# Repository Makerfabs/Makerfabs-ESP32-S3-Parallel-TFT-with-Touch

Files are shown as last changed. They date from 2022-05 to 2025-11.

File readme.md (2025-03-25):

# Makerfabs ESP32-S3 Parallel TFT with Touch

```c++
/*
Version:		V1.3
Author:			Vincent
Create Date:	2022/5/24
Note:
	2022/12/29	V1.3:Change wiki link.
	2022/10/7	V1.2:Add USB HID example.
	2022/10/7	V1.1:Add USB HID example.
*/
```


[toc]

# Makerfabs

[Makerfabs home page](https://www.makerfabs.com/)

[Makerfabs Wiki](https://wiki.makerfabs.com/)

# Makerfabs ESP32-S3 Parallel TFT with Touch
## Intruduce

Product Link ：[ESP32-S3 Parallel TFT with Touch 3.5'' ILI9488](https://www.makerfabs.com/esp32-s3-parallel-tft-with-touch-ili9488.html)

Wiki Link : [ESP32-S3 Parallel 3.5'' TFT with Touch](https://wiki.makerfabs.com/ESP32_S3_Parallel_3.5_TFT_with_Touch.html)

The 3.5" 320x480 TFT LCD driver is ILI9488, it uses 16bits parallel line for communication with ESP32-S3, the main clock could be up to 20MHz, make the display smooth enough for videos; You can freely use some of Mabee pins(A I2c and a IOs) with the breakout connectors, to connect the ESP32-S3 display with sensors/ actuators, suitable for IoT applications.

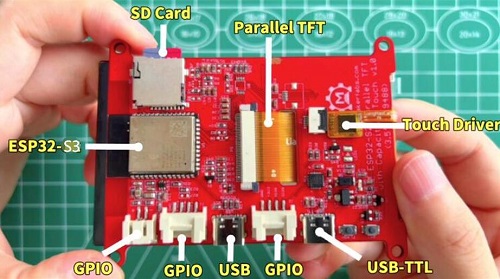
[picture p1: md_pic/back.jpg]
back


## Feature

- Wi-Fi (2.4 GHz band)
- Bluetooth Low Energy
- Dual high performance Xtensa® 32-bit LX7 CPU cores
- Ultra Low Power co-processor running either RISC-V or FSM core
- Multiple peripherals
- Built-in security hardware
- USB OTG interface
- USB Serial/JTAG Controller
- Arduino Compatible: You can play it with Arduino IDE
- LCD 3.5 inch Amorphous-TFT-LCD (Thin Film Transistor Liquid Crystal Display) for mobile-phone or handy electrical equipment
- LCD Driver: ILI9488(16bits parallel line)
- LCD Resolution: 320*480
- FT6236 Series ICs are single-chip capacitive touch panel controller IC with a built-in 16 bit enhanced Micro-controller unit (MCU)
- NS2009: A 4-wire resistive touch screen control circuit with I2C interface, which contains A 12-bit resolution A/D converter
- Power supply: 5V, Type-C USB
- Micro SD card slot on the board
- Dual USB Type-C: one for native USB and one for USB-to-UART
- Two Mabee interfaces
- Board size: 66mm * 85mm

# Code Explain

## Complier Option

- Install board : ESP32 .
- Install library : LovyanGFX library. 
- Edit the code based on the touch screen. If you use resistive screen, choice NS2009_TOUCH. If you use capacitive screen, choice FT6236_TOUCH. 
- Use type-c use cable connect USB-TTL to PC.
- Upload codes, select "ESP32-S3 DEV Module" and "UART0"

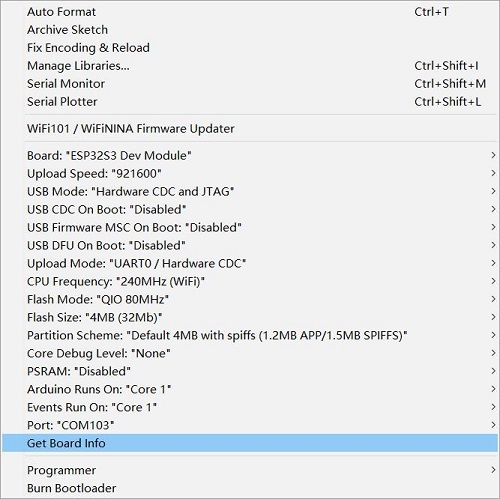
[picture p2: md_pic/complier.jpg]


## Firmware

### SD16_3.5

Factory firmware. First run the boot self-test to check the hardware. Press down the middle of the touch screen as prompted to display a LOGO picture on the SD card. Finally, print the touch coordinates in the serial port.

## Example

### touch_keyboard

The ESP32S3 native USB is used, which can be used as a USB HID to simulate a keyboard.

You can input text, key combination, enter key, and connect to the NTP server through WiFi, output real-time time.

### touch_keyboard V2.0

Added an inherited three custom keyboard keyboard Demo, including text input + key combination, numeric keypad, arrow keys + space.

### PDQgraphicstest

Arduino GFX Library display demo.

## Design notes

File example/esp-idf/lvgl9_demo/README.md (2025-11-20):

## How to use example

Before you begin, please ensure that esp-idf is installed on your computer. If not, click [Get Started with esp-idf](https://wiki.makerfabs.com/Get_Start_with_ESP-IDF.html) to complete the installation.

Launch the project in Visual Studio Code.

Set espressif Device Target **ESP32S3**



Use USB-C to connect the board and PC, select the corresponding port and Flash Device.



**Result**

lvgl_widgets

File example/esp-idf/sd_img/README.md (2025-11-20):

## How to use example

> It is recommended to use the [conversion tool](https://lvgl.io/tools/imageconverter) provided by LVGL to convert the image into a bin file, and then store it on the SD card. This way, the CPU does not need to decode the image in real time, thereby improving the refresh speed.

Before you begin, please ensure that esp-idf is installed on your computer. If not, click [Get Started with esp-idf](https://wiki.makerfabs.com/Get_Start_with_ESP-IDF.html) to complete the installation.

Launch the project in Visual Studio Code.

Set espressif Device Target **ESP32S3**



Use USB-C to connect the board and PC, select the corresponding port and Flash Device.



**Result**:

sd_img

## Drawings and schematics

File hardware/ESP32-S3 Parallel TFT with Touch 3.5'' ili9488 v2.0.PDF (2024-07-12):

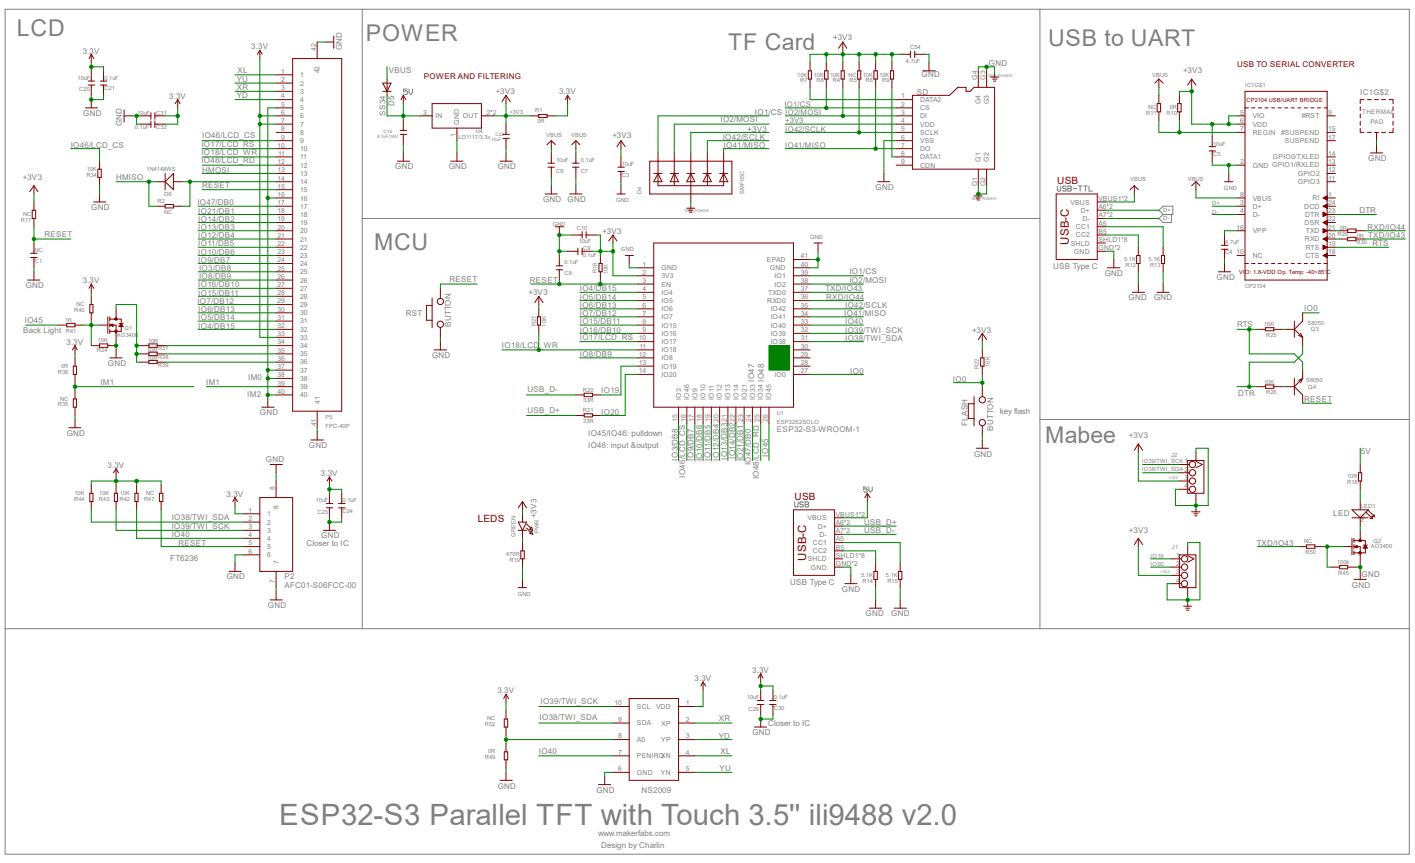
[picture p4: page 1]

USB Type C TF Card

USB TO SERIAL CONVERTER

VIO: 1.8-VDD Op. Temp: -40~85°C USB⁻C USB⁻C

ESP32-S3 Parallel TFT with Touch 3.5'' ili9488 v2.0

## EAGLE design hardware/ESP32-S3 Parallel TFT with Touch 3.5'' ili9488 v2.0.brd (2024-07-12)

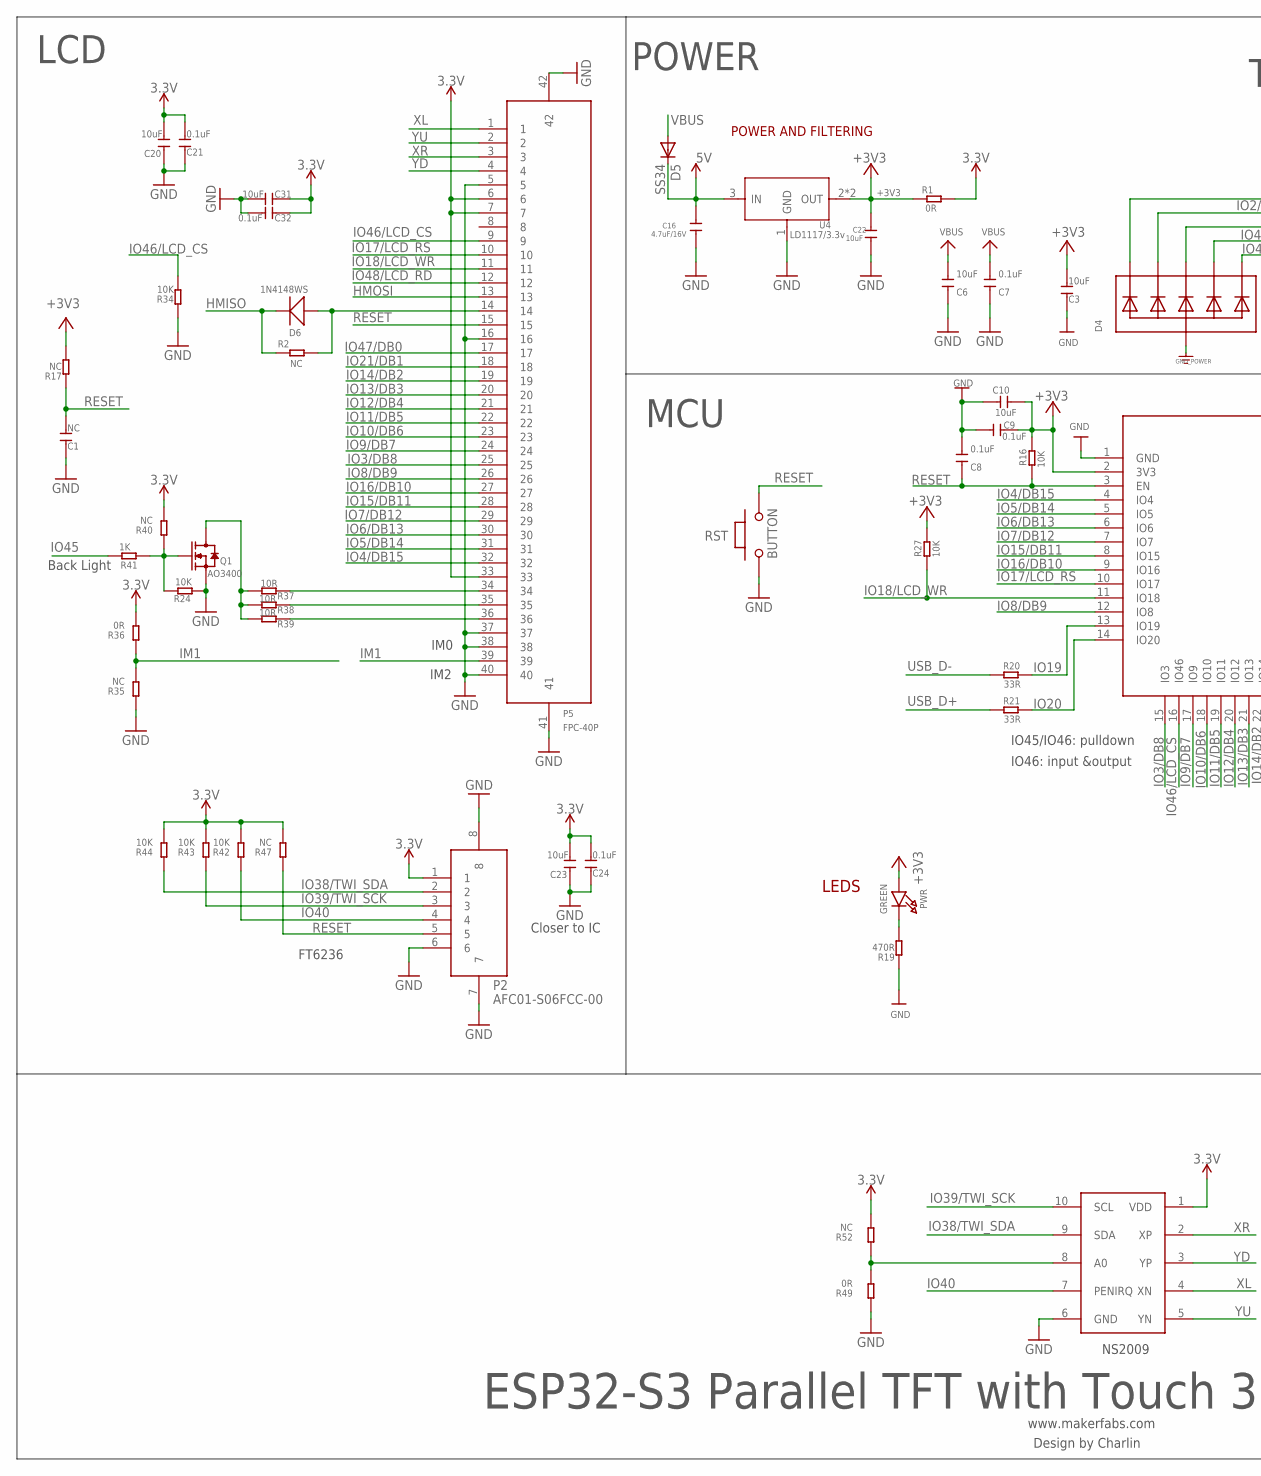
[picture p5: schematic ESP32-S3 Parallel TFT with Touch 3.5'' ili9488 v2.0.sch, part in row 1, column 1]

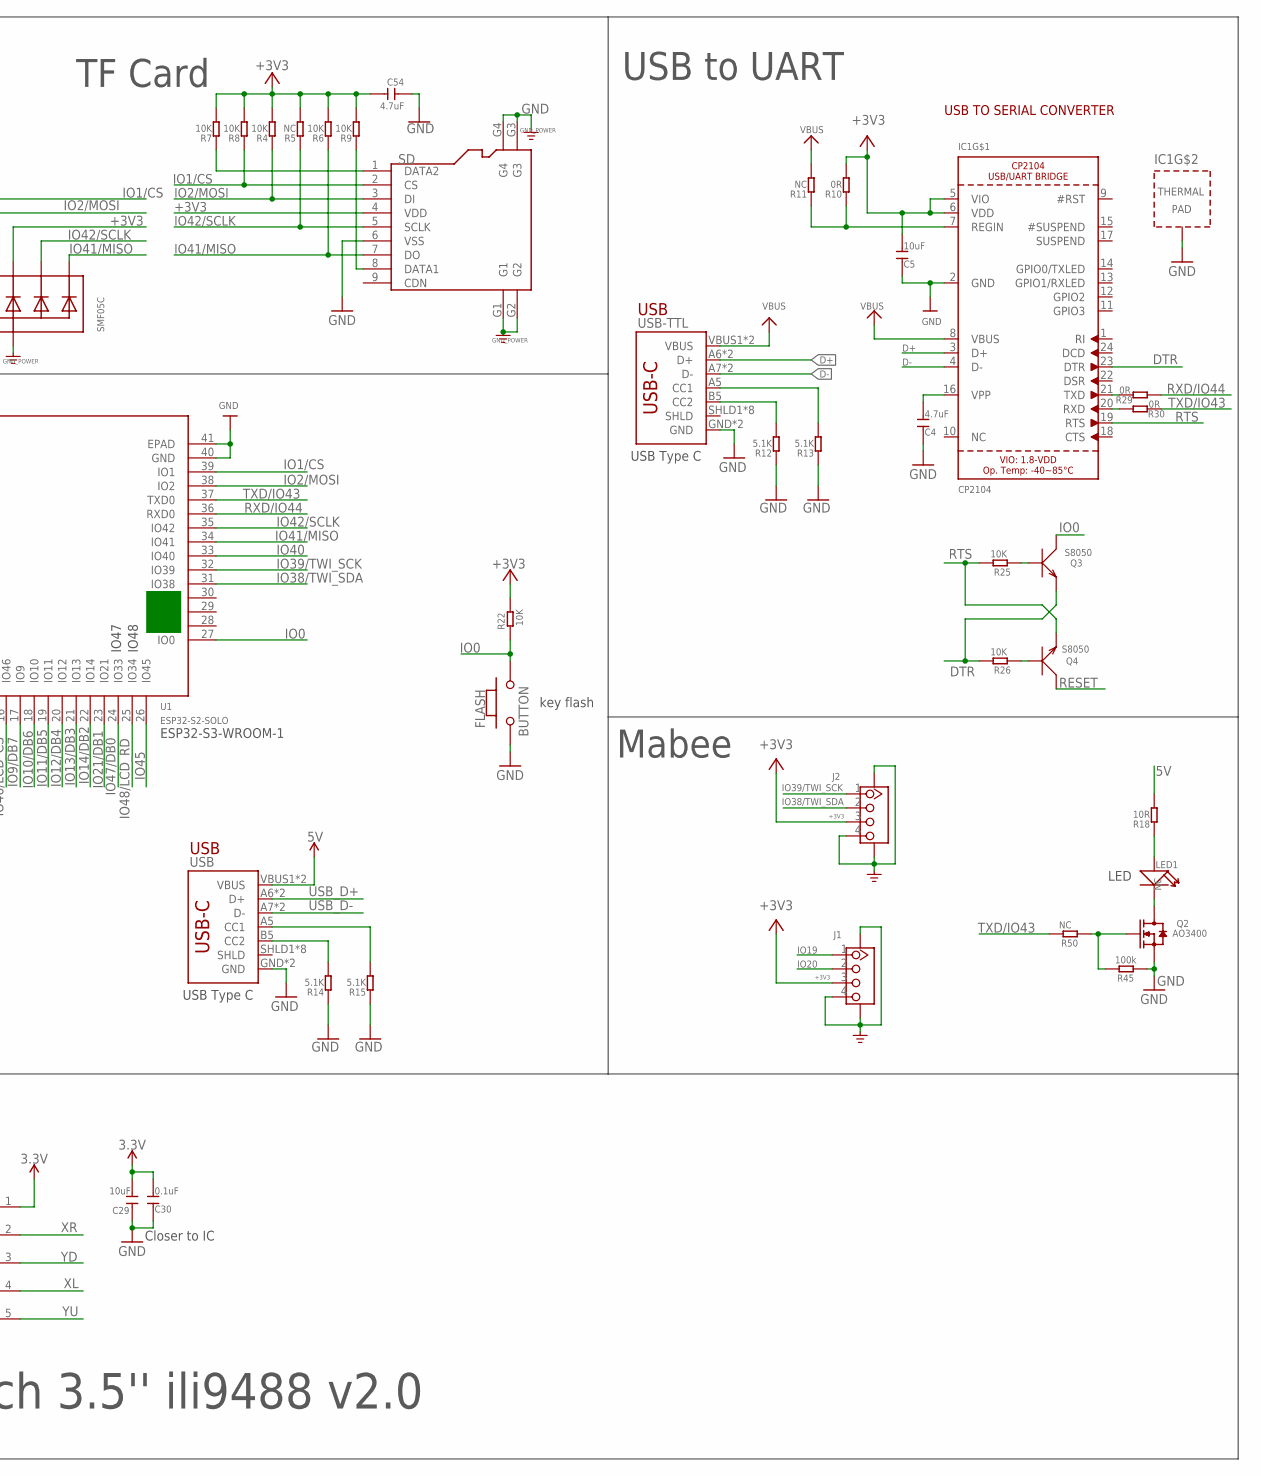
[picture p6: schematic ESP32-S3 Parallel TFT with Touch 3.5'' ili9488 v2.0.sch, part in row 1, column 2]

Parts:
C1: NC; DISCRETE_C0603
C3, C5, C6, C10, C20, C23, C29, C31: 10uF; DISCRETE_C0603
C4, C54: 4.7uF; DISCRETE_C0603
C7, C8, C9, C21, C24, C30, C32: 0.1uF; DISCRETE_C0603
C16: 4.7uF/16V; 0603
C22: 10uF; 0603
D4: SMF05C; SOT363
D5: SS34; DO-214AC
D6: 1N4148WS; SOD323
FLASH: BUTTON; 157SW
IC1: CP2104; QFN24_4MM_SMSC
J1, J2: GROVE-CONNECTOR-SMD'90D'; HW4-SMD-2.0-90D
LED1: NC; DISCRETE_LED-3528
P2: AFC01-S06FCC-00; SMD8-50P-740L535W
P5: FPC-40P; SMD42-50P-2560L490W
PWR: GREEN; CHIPLED_0805_NOOUTLINE
Q1, Q2: AO3400; SOT23@1
Q3, Q4: S8050; SOT23
R1, R29, R30: 0R; R0603
R2, R50: NC; R0603
R4, R6, R7, R8, R9, R24, R34, R42, R43, R44: 10K; DISCRETE_R0603
R5, R11, R17, R35, R40, R47, R52: NC; DISCRETE_R0603
R10, R36, R49: 0R; DISCRETE_R0603
R12, R13, R14, R15: 5.1K; DISCRETE_R0603
R16, R22, R25, R26, R27: 10K; R0603
R18, R37, R38, R39: 10R; DISCRETE_R0603
R19: 470R; DISCRETE_R0603
R20, R21: 33R; R0603
R41: 1K; DISCRETE_R0603
R45: 100k; R0603
RST: BUTTON; 157SW
SD: HOLDER-MICROSD-9P; 9P-SMD-W/-RING
U1: ESP32­S2­SOLO; ESP32-­S2-­SOLO
U4: LD1117/3.3v; SOT89
U8: NS2009; MSOP10
USB: USB_C5; USB-C-16P-5
USB-TTL: USB_C5; USB-C-16P-5

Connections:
3.3V: C20.2, C21.2, C23.2, C24.2, C29.2, C30.2, C31.1, C32.1, P2.1, P5.6, P5.7, P5.33, R1.2, R36.2, R40.2, R42.2, R43.2, R44.2, R47.2, R52.2, U8.1 (VDD)
5V: C16.1, D5.C, R18.2, U4.3 (IN), USB.VBUS1 (VBUS), USB.VBUS2 (VBUS)
+3V3: C3.2, C5.2, C9.1, C10.1, C22.1, C54.2, D4.4 (C3), IC1.5 (VIO), IC1.6 (VDD), J1.3, J2.3, PWR.A, R1.1, R4.2, R5.2, R6.2, R7.2, R8.2, R9.2, R10.2, R16.2, R17.2, R22.2, R27.2, SD.4 (VDD), U1.2 (3V3), U4.2 (OUT), U4.4 (OUT)
D+: IC1.3 (D+), USB-TTL.A6 (D+), USB-TTL.B6 (D+)
D-: IC1.4 (D-), USB-TTL.A7 (D-), USB-TTL.B7 (D-)
DTR: IC1.23 (DTR), Q3.2 (E), R26.2
GND: C1.1, C3.1, C4.1, C5.1, C6.1, C7.1, C8.2, C9.2, C10.2, C16.2, C20.1, C21.1, C22.2, C23.1, C24.1, C29.1, C30.1, C31.2, C32.2, C54.1, D4.2 (A), FLASH.1, IC1.2 (GND), IC1.THERM (TP), J1.4, J1.SS1, J1.SS2, J2.4, J2.SS1, J2.SS2, P2.6, P2.7, P2.8, P5.5, P5.16, P5.37, P5.38, P5.40, P5.41, P5.42, Q1.2 (S), Q2.2 (S), R12.1, R13.1, R14.1, R15.1, R19.1, R24.1, R34.1, R35.1, R45.1, R49.1, RST.1, SD.6 (VSS), SD.G1, SD.G2, SD.G3, SD.G4, U1.1 (GND), U1.40 (GND), U1.41 (EPAD), U4.1 (GND), U8.6 (GND), USB.GND, USB.GND2 (GND), USB-TTL.GND, USB-TTL.GND2 (GND)
HMISO: D6.-, R2.1
HMOSI: P5.13
IM1: P5.39, R35.2, R36.1
IO0: FLASH.2, Q3.3 (C), R22.1, U1.27 (IO0)
IO1/CS: D4.1 (C1), R8.1, SD.2 (CS), U1.39 (IO1)
IO2/MOSI: D4.3 (C2), R4.1, SD.3 (DI), U1.38 (IO2)
IO3/DB8: P5.25, U1.15 (IO3)
IO4/DB15: P5.32, U1.4 (IO4)
IO5/DB14: P5.31, U1.5 (IO5)
IO6/DB13: P5.30, U1.6 (IO6)
IO7/DB12: P5.29, U1.7 (IO7)
IO8/DB9: P5.26, U1.12 (IO8)
IO9/DB7: P5.24, U1.17 (IO9)
IO10/DB6: P5.23, U1.18 (IO10)
IO11/DB5: P5.22, U1.19 (IO11)
IO12/DB4: P5.21, U1.20 (IO12)
IO13/DB3: P5.20, U1.21 (IO13)
IO14/DB2: P5.19, U1.22 (IO14)
IO15/DB11: P5.28, U1.8 (IO15)
IO16/DB10: P5.27, U1.9 (IO16)
IO17/LCD_RS: P5.10, U1.10 (IO17)
IO18/LCD_WR: P5.11, R27.1, U1.11 (IO18)
IO19: J1.1, R20.2, U1.13 (IO19)
IO20: J1.2, R21.2, U1.14 (IO20)
IO21/DB1: P5.18, U1.23 (IO21)
IO38/TWI_SDA: J2.2, P2.2, R44.1, U1.31 (IO38), U8.9 (SDA)
IO39/TWI_SCK: J2.1, P2.3, R43.1, U1.32 (IO39), U8.10 (SCL)
IO40: P2.4, R42.1, U1.33 (IO40), U8.7 (PENIRQ)
IO41/MISO: D4.6 (C5), R6.1, SD.7 (DO), U1.34 (IO41)
IO42/SCLK: D4.5 (C4), R5.1, SD.5 (SCLK), U1.35 (IO42)
IO45: R41.2, U1.26 (IO45)
IO46/LCD_CS: P5.9, R34.2, U1.16 (IO46)
IO47/DB0: P5.17, U1.24 (IO33)
IO48/LCD_RD: P5.12, U1.25 (IO34)
unnamed: C4.2, IC1.16 (VPP)
unnamed: Q4.1 (B), R26.1
unnamed: Q3.1 (B), R25.1
unnamed: D6.+, P5.14, R2.2
unnamed: Q2.1 (G), R45.2, R50.1
unnamed: R15.2, USB.A5 (CC1)
unnamed: PWR.C, R19.2
unnamed: LED1.1 (+), R18.1
unnamed: LED1.2 (-), Q2.3 (D)
unnamed: R13.2, USB-TTL.A5 (CC1)
unnamed: R12.2, USB-TTL.B5 (CC2)
unnamed: IC1.7 (REGIN), R10.1, R11.1
unnamed: R14.2, USB.B5 (CC2)
unnamed: IC1.21 (TXD), R29.2
unnamed: IC1.20 (RXD), R30.2
unnamed: P5.34, R37.1
unnamed: P5.35, R38.1
unnamed: P5.36, R39.1
unnamed: Q1.1 (G), R24.2, R40.1, R41.1
unnamed: Q1.3 (D), R37.2, R38.2, R39.2
unnamed: R49.2, R52.1, U8.8 (A0)
unnamed: R7.1, SD.1 (DATA2)
unnamed: R9.1, SD.8 (DATA1)
RESET: C1.2, C8.1, P2.5, P5.15, Q4.3 (C), R16.1, R17.1, R47.1, RST.2, U1.3 (EN)
RTS: IC1.19 (RTS), Q4.2 (E), R25.2
RXD/IO44: R29.1, U1.36 (RXD0)
TXD/IO43: R30.1, R50.2, U1.37 (TXD0)
USB_D+: R21.1, USB.A6 (D+), USB.B6 (D+)
USB_D-: R20.1, USB.A7 (D-), USB.B7 (D-)
VBUS: C6.2, C7.2, D5.A, IC1.8 (VBUS), R11.2, USB-TTL.VBUS1 (VBUS), USB-TTL.VBUS2 (VBUS)
XL: P5.1, U8.4 (XN)
XR: P5.3, U8.2 (XP)
YD: P5.4, U8.3 (YP)
YU: P5.2, U8.5 (YN)

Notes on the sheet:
www.makerfabs.com
Design by Charlin
USB
LEDS
POWER AND FILTERING
USB TO SERIAL CONVERTER
key flash
ESP32-S3 Parallel TFT with Touch 3.5'' ili9488 v2.0
POWER
USB to UART
USB Type C
TF Card
LED
NS2009
FT6236
Closer to IC
Back Light
IM0
IM2
IO45/IO46: pulldown
IO46: input &output
Mabee
LCD
MCU
ESP32-S3-WROOM-1
IO47
IO48

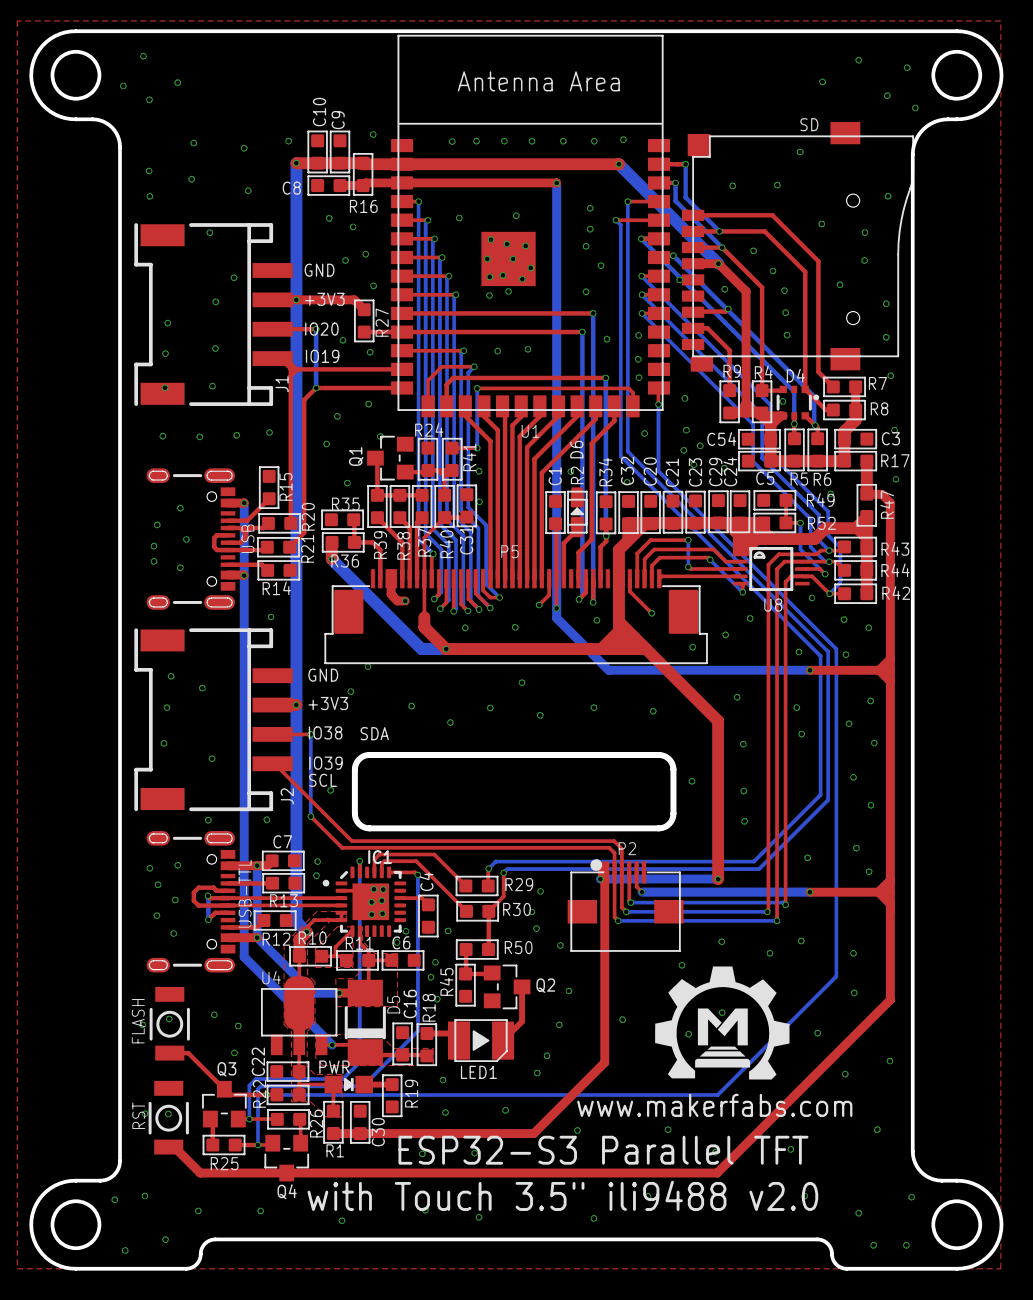
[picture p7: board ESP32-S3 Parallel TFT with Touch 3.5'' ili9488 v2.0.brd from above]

Board: 2 copper layers, 66.1 x 84.3 mm, 86 parts (0 on the bottom side), 74 nets.

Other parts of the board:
U$1: MAKERFABS_0.3

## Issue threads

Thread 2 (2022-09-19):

What type of connector is the 4-pin?

jonsmirl, 2022-09-19:
It is not microJST, I tried that. The 2-pin is microJST.

jayv, 2023-12-09:
@jonsmirl did you ever find out? before I solder a 2.5 JST connector to the back of those?

jonsmirl, 2023-12-10:
I think it was this one:
https://www.amazon.com/gp/product/B01CNZ9RJO/ref=ppx_yo_dt_b_search_asin_title

jayv, 2023-12-10:
Thanks! I’ve also come to learn about the “Grove” connector effort, turns out I already have some compatible cables from another IOT kit. Thx!

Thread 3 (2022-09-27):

Improved display driver w/ i8080 acceleration

codewitch-honey-crisis, 2022-09-27:
Hey folks! Great product, love it!

However, your firmware doesn't really take advantage of its performance features.

You use LoyvanGFX to do the display, but it's not DMA capable, and bit bangs the pins, but the S3 has a hardware i8080 parallel driver.

I wrote a new graphics driver to use it.

I got 37 fps with your firmware running LVGL benchmarks

I got 58 fps with my driver.

If you're interested, ping me back and I'll fork and do a pull request with the improved code.

nstansbury, 2023-08-17:
@codewitch-honey-crisis Did you submit a PR for these changes? This looks like an unmaintained codebase, so if you have forked this please share

codewitch-honey-crisis, 2023-08-17:
I haven't. I suppose I could. I didn't go through the trouble of forking the makerfabs code because I have my own libs for all of its hardware. The key to better performance is to ditch Lovyan and use the ESP LCD Panel API directly, via calling into the ESP-IDF.

Ldalvik, 2023-08-19:
You'd be doing a huge favor to tons of future projects if you managed to write a good driver for this specific device, it's always disappointing seeing these kinds of things not being used to the full potentially.

codewitch-honey-crisis, 2023-08-19:
I linked to a driver in the comment you responded to.

Ldalvik, 2023-08-19:
Oh wow, I completely glanced over that and thought you only had a platformIO version. I might try to port it myself if you haven't already planned on it, I'd love to be able to write simpler code using the faster refresh rate. Is playing a video from the SD card affected by your code too?

codewitch-honey-crisis, 2023-08-19:
It is a platformIO library, but it can be used without PIO. You just need to put the two C files in the project somehow.

jonsmirl, 2024-04-11:
LCD and touch are directly supported by IDF and Component registry now.
https://github.com/jonsmirl/esp_idf_makerfab

It is very similar to your code.

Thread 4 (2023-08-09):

Touch not rotating

phpbbireland, 2023-08-09:
In the _**touch_keyboard_v2.ino**_ file, I rotated the display in **SPI_9488.h** to landscape i.e., ```cfg.offset_rotation = 1;```
I edited the code to display buttons in a 4x3 layout in (landscape mode), everything is resized and fits neatly, there's just one problem... the touch appears to return position as if in portrait mode...

Is there a method to tell the touch to rotate too?

Mike

phpbbireland, 2023-08-19:
I have overcome this by editing my code, so I guess I will close the issue...

Closed 2023-08-19.

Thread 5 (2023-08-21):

Compile error

phpbbireland, 2023-08-21:
Compile error in:
Makerfabs-ESP32-S3-Parallel-TFT-with-Touch-main/example/touch_keyboard_v2/

```
'Bus_Parallel16' in namespace 'lgfx' does not name a type
```

Everything working fine for the SPI version...
Any help appreciated...

phpbbireland, 2023-08-23:
Appears eyesight is failing... it was S2 not S3 board... apologies...
Now it compiles fine but I am getting a white screen, back to the drawing board...

Closed 2023-08-23.

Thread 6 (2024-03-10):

Esp32 and 3.5inch ili9488 16bit interface

Kiara-Mugambi, 2024-03-10:
Am trying to obtain the code between esp and the TFT that uses 16bit interface and ft6236 capacitive touch panel

Kiara-Mugambi, 2024-03-11:
Am trying to obtain the code between esp and the TFT that uses 16bit interface and ft6236 capacitive touch panel

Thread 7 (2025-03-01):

ESP32-S3 Parallel TFT with Touch 3.5'' ili9488 - SPK connector?

Dario-Ciceri, 2025-03-01:
Hello, I noticed that there is an SPK connector on the board, and I guess it is therefore possible to connect a speaker. However, I cannot find in the schematic what PINs this connector is connected to.

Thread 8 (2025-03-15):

Repeated Restarts or Blank White Display - Version 1.0

HopWorks, 2025-03-15:
I tried running the two examples (touch_keyboard and touch_keyboard_v2) on my  Makerfabs-ESP32-S3-Parallel-TFT-with-Touch 3.5" Version 1.0 (WROOM1 N16R2) with current libraries and the ESP32S3 device reboots repeatedly using both PlatformIO and Arduino IDE. I then rolled back to the library versions shown in the FAQ at [https://wiki.makerfabs.com/MaTouch_S3_Parallel_3.5_TFT_with_Touch.html#faq](url) and after correcting the spell-check errors (defualt to default) I flashed and no more restarts but I get a white screen with nothing displayed. The serial monitor still shows feedback when I press portions of the screen, telling me that the code did not crash and the touch portion is working.

I suspect changes in the wiring with the upgrade to Version 2.0 as noted in the FAQ.
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

Is this the cause of my issues? If so, where is WR, RS, and CS statically declared in the libraries? I cannot find any declarations in the example code. Thanks

HopWorks, 2025-03-15:
I solved it.  Since I had seen LCD_CS and LCD_BLK defined separately, I tried defining LCD_WR and LCD_RS in the main code and in the header file to see if that would override but it did not.

The header file `Parallel16_9488.h` (LGFX class) needs to be changed back to the correct pin settings for the version 1.0 board,
after `class LGFX : public lgfx::LGFX_Device`...
`            //cfg.pin_wr = 18; // SETTING FOR BOARD VERSION 2.0
            cfg.pin_wr = 35; // pin number to which WR is connected
            cfg.pin_rd = 48; // pin number connecting RD
            //cfg.pin_rs = 17; // SETTING FOR BOARD VERSION 2.0
            cfg.pin_rs = 36; // pin number connecting RS (D/C)`

The library is found in both keyboard examples. The settings are also in another library `S3_Parallel16_ili9488.h` in the `ESP32S3_SGP30_WEBSERVER_V1.2` example.

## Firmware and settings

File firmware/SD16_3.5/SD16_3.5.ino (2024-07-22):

#define LGFX_USE_V1

#include "FS.h"
#include "SD.h"
#include "SPI.h"
#include <LovyanGFX.hpp>

#define I2C_SCL 39
#define I2C_SDA 38

//#define NS2009_TOUCH  //Resistive screen driver
#define FT6236_TOUCH //Capacitive screen driver

#ifdef NS2009_TOUCH
#include "NS2009.h"
const int i2c_touch_addr = NS2009_ADDR;
#define get_pos ns2009_pos
#endif

#ifdef FT6236_TOUCH
#include "FT6236.h"
const int i2c_touch_addr = TOUCH_I2C_ADD;
#define get_pos ft6236_pos
#endif

#define SPI_MOSI 2 //1
#define SPI_MISO 41
#define SPI_SCK 42
#define SD_CS 1 //2

#define LCD_CS 46
#define LCD_BLK 45


class LGFX : public lgfx::LGFX_Device
{
    // lgfx::Panel_ILI9341 _panel_instance;
    lgfx::Panel_ILI9488 _panel_instance;
    lgfx::Bus_Parallel16 _bus_instance; // 8ビットパラレルバスのインスタンス (ESP32のみ)

public:
    // コンストラクタを作成し、ここで各種設定を行います。
    // クラス名を変更した場合はコンストラクタも同じ名前を指定してください。
    LGFX(void)
    {
        {                                      // バス制御の設定を行います。
            auto cfg = _bus_instance.config(); // バス設定用の構造体を取得します。

            // 16位设置
            cfg.port = 0;              // 使用するI2Sポートを選択 (0 or 1) (ESP32のI2S LCDモードを使用します)
            cfg.freq_write = 20000000; // 送信クロック (最大20MHz, 80MHzを整数で割った値に丸められます)
            cfg.pin_wr = 18;           // WR を接続しているピン番号
            cfg.pin_rd = 48;           // RD を接続しているピン番号
            cfg.pin_rs = 17;           // RS(D/C)を接続しているピン番号

            cfg.pin_d0 = 47;
            cfg.pin_d1 = 21;
            cfg.pin_d2 = 14;
            cfg.pin_d3 = 13;
            cfg.pin_d4 = 12;
            cfg.pin_d5 = 11;
            cfg.pin_d6 = 10;
            cfg.pin_d7 = 9;
            cfg.pin_d8 = 3;
            cfg.pin_d9 = 8;
            cfg.pin_d10 = 16;
            cfg.pin_d11 = 15;
            cfg.pin_d12 = 7;
            cfg.pin_d13 = 6;
            cfg.pin_d14 = 5;
            cfg.pin_d15 = 4;

            _bus_instance.config(cfg);              // 設定値をバスに反映します。
            _panel_instance.setBus(&_bus_instance); // バスをパネルにセットします。
        }

        {                                        // 表示パネル制御の設定を行います。
            auto cfg = _panel_instance.config(); // 表示パネル設定用の構造体を取得します。

            cfg.pin_cs = -1;   // CS要拉低
            cfg.pin_rst = -1;  // RST和开发板RST相连
            cfg.pin_busy = -1; // BUSYが接続されているピン番号 (-1 = disable)

            // ※ 以下の設定値はパネル毎に一般的な初期値が設定されていますので、不明な項目はコメントアウトして試してみてください。

            cfg.memory_width = 320;   // ドライバICがサポートしている最大の幅
            cfg.memory_height = 480;  // ドライバICがサポートしている最大の高さ
            cfg.panel_width = 320;    // 実際に表示可能な幅
            cfg.panel_height = 480;   // 実際に表示可能な高さ
            cfg.offset_x = 0;         // パネルのX方向オフセット量
            cfg.offset_y = 0;         // パネルのY方向オフセット量
            cfg.offset_rotation = 0;  // 回転方向の値のオフセット 0~7 (4~7は上下反転)
            cfg.dummy_read_pixel = 8; // ピクセル読出し前のダミーリードのビット数
            cfg.dummy_read_bits = 1;  // ピクセル以外のデータ読出し前のダミーリードのビット数
            cfg.readable = true;      // データ読出しが可能な場合 trueに設定
            cfg.invert = false;       // パネルの明暗が反転してしまう場合 trueに設定
            cfg.rgb_order = false;    // パネルの赤と青が入れ替わってしまう場合 trueに設定
            cfg.dlen_16bit = true;    // データ長を16bit単位で送信するパネルの場合 trueに設定
            cfg.bus_shared = true;    // SDカードとバスを共有している場合 trueに設定(drawJpgFile等でバス制御を行います)

            _panel_instance.config(cfg);
        }

        setPanel(&_panel_instance); // 使用するパネルをセットします。
    }
};

LGFX lcd;
int pos[2] = {0, 0};
int err_code = 0;

void setup()
{
    pinMode(LCD_CS, OUTPUT);
    pinMode(LCD_BLK, OUTPUT);

    digitalWrite(LCD_CS, LOW);
    digitalWrite(LCD_BLK, HIGH);

    Serial.begin(115200);

    lcd.init();
    lcd.fillScreen(TFT_BLUE);
    lcd.setTextColor(TFT_YELLOW);
    lcd.setTextSize(2);
    lcd.setCursor(0, 0);
    lcd.print("Makerfabs ESP32-S3");
    lcd.setCursor(0, 16);
    lcd.print("Parallel TFT with Touch");

    SPI.begin(SPI_SCK, SPI_MISO, SPI_MOSI);

    lcd.setCursor(0, 32);
    if (SD_init())
    {
        lcd.print("ERROR:   SD");
        err_code += 1;
    }
    else
        lcd.print("SD INIT OVER");

    //I2C init
    Wire.begin(I2C_SDA, I2C_SCL);
    byte error, address;

    Wire.beginTransmission(i2c_touch_addr);
    error = Wire.endTransmission();

    lcd.setCursor(0, 48);
    if (error == 0)
    {
        Serial.print("I2C device found at address 0x");
        Serial.print(i2c_touch_addr, HEX);
        Serial.println("  !");
        lcd.print("TOUCH INIT OVER");
    }
    else
    {
        Serial.print("Unknown error at address 0x");
        Serial.println(i2c_touch_addr, HEX);
        lcd.print("ERROR:   TOUCH");
        err_code += 1;
    }

    lcd.setCursor(0, 64);
    if (err_code)
    {

        lcd.print("SOMETHING WRONG");
        while (1)
            ;
    }
    else
        lcd.print("ALL SUCCESS");

    lcd.setRotation(1);

    int rect_length = 40;

    lcd.fillRect(240 - rect_length, 160 - rect_length, rect_length * 2, rect_length * 2, TFT_RED);

    lcd.setCursor(100, 10);
    lcd.print(F("TOUCH RED RECT"));

    while (1)
    {
        if (get_pos(pos))
        {
            if (pos[0] < 160 + rect_length && pos[0] > 160 - rect_length && pos[1] < 240 + rect_length && pos[1] > 240 - rect_length)
                break;
        }
        delay(10);
        Serial.println("No touch");
    }

    lcd.setRotation(3);
    print_img(SD, "/logo.bmp", 480, 320);
}

void loop()
{
    if (get_pos(pos))
    {
        Serial.println((String)"x=" + pos[0] + ",y=" + pos[1]);
    }

    delay(100);
}

int SD_init()
{

    if (!SD.begin(SD_CS))
    {
        Serial.println("Card Mount Failed");
        return 1;
    }
    uint8_t cardType = SD.cardType();

    if (cardType == CARD_NONE)
    {
        Serial.println("No SD card attached");
        return 1;
    }

    Serial.print("SD Card Type: ");
    if (cardType == CARD_MMC)
    {
        Serial.println("MMC");
    }
    else if (cardType == CARD_SD)
    {
        Serial.println("SDSC");
    }
    else if (cardType == CARD_SDHC)
    {
        Serial.println("SDHC");
    }
    else
    {
        Serial.println("UNKNOWN");
    }

    uint64_t cardSize = SD.cardSize() / (1024 * 1024);
    Serial.printf("SD Card Size: %lluMB\n", cardSize);
    listDir(SD, "/", 2);

    Serial.println("SD init over.");
    return 0;
}

void listDir(fs::FS &fs, const char *dirname, uint8_t levels)
{
    Serial.printf("Listing directory: %s\n", dirname);

    File root = fs.open(dirname);
    if (!root)
    {
        Serial.println("Failed to open directory");
        return;
    }
    if (!root.isDirectory())
    {
        Serial.println("Not a directory");
        return;
    }

    File file = root.openNextFile();
    while (file)
    {
        if (file.isDirectory())
        {
            Serial.print("  DIR : ");
            Serial.println(file.name());
            if (levels)
            {
                listDir(fs, file.name(), levels - 1);
            }
        }
        else
        {
            Serial.print("  FILE: ");
            Serial.print(file.name());
            Serial.print("  SIZE: ");
            Serial.println(file.size());
        }
        file = root.openNextFile();
    }
}

void readFile(fs::FS &fs, const char *path)
{
    Serial.printf("Reading file: %s\n", path);

    File file = fs.open(path);
    if (!file)
    {
        Serial.println("Failed to open file for reading");
        return;
    }

    Serial.print("Read from file: ");
    while (file.available())
    {
        Serial.write(file.read());
    }
    file.close();
}

void writeFile(fs::FS &fs, const char *path, const char *message)
{
    Serial.printf("Writing file: %s\n", path);

    File file = fs.open(path, FILE_WRITE);
    if (!file)
    {
        Serial.println("Failed to open file for writing");
        return;
    }
    if (file.print(message))
    {
        Serial.println("File written");
    }
    else
    {
        Serial.println("Write failed");
    }
    file.close();
}

void appendFile(fs::FS &fs, const char *path, const char *message)
{
    Serial.printf("Appending to file: %s\n", path);

    File file = fs.open(path, FILE_APPEND);
    if (!file)
    {
        Serial.println("Failed to open file for appending");
        return;
    }
    if (file.print(message))
    {
        Serial.println("Message appended");
    }
    else
    {
        Serial.println("Append failed");
    }
    file.close();
}

//Display image from file
int print_img(fs::FS &fs, String filename, int x, int y)
{
    File f = fs.open(filename, "r");
    if (!f)
    {
        Serial.println("Failed to open file for reading");
        f.close();
        return 0;
    }

    f.seek(54);
    int X = x;
    int Y = y;
    uint8_t RGB[3 * X];
    for (int row = 0; row < Y; row++)
    {
        f.seek(54 + 3 * X * row);
        f.read(RGB, 3 * X);
        lcd.pushImage(0, row, X, 1, (lgfx::rgb888_t *)RGB);
    }

    f.close();
    return 0;
}

//Display image from file
//BMP is 32 bit...
int print_img_small(fs::FS &fs, String filename, int x, int y, int w, int h)
{
    File f = fs.open(filename, "r");
    if (!f)
    {
        Serial.println("Failed to open file for reading");
        f.close();
        return 0;
    }

    f.seek(54);
    int X = w;
    int Y = h;
    uint8_t RGB[3 * X];
    uint8_t RGBA[4 * X];
    for (int row = 0; row < Y; row++)
    {
        f.seek(54 + 4 * X * row);
        f.read(RGBA, 4 * X);

        for (int i = 0; i < X; i++)
        {
            RGB[3 * i] = RGBA[4 * X - 4 * i - 4];
            RGB[3 * i + 1] = RGBA[4 * X - 4 * i - 3];
            RGB[3 * i + 2] = RGBA[4 * X - 4 * i - 2];
        }
        lcd.pushImage(x, y + row, X, 1, (lgfx::rgb888_t *)RGB);
    }

    f.close();
    return 0;
}

//transform touch screen pos
void pos_rotation(int pos[2], int rotation)
{
    if (pos[0] == -1)
        return;
    if (rotation == 0)
    {
        return;
    }
    if (rotation == 3)
    {
        int tempx = 480 - pos[1];
        int tempy = pos[0];
        pos[0] = tempx;
        pos[1] = tempy;
    }
}

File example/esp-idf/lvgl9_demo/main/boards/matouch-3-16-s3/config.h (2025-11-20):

#ifndef _BOARD_CONFIG_H_
#define _BOARD_CONFIG_H_

#include <driver/gpio.h>

#define AUDIO_INPUT_SAMPLE_RATE  16000
#define AUDIO_OUTPUT_SAMPLE_RATE 16000

// 如果使用 Duplex I2S 模式，请注释下面一行
// #define AUDIO_I2S_METHOD_SIMPLEX

#ifdef AUDIO_I2S_METHOD_SIMPLEX

#define AUDIO_I2S_MIC_GPIO_WS       GPIO_NUM_2
#define AUDIO_I2S_MIC_GPIO_SCK      GPIO_NUM_42
#define AUDIO_I2S_MIC_GPIO_DIN      GPIO_NUM_41
#define AUDIO_I2S_SPK_GPIO_DOUT     GPIO_NUM_19
#define AUDIO_I2S_SPK_GPIO_BCLK     GPIO_NUM_20
#define AUDIO_I2S_SPK_GPIO_LRCK     GPIO_NUM_1

#else

#define AUDIO_I2S_GPIO_WS           GPIO_NUM_43
#define AUDIO_I2S_GPIO_BCLK         GPIO_NUM_44
#define AUDIO_I2S_GPIO_DIN          GPIO_NUM_2
#define AUDIO_I2S_GPIO_DOUT         GPIO_NUM_19

#endif


#define BUILTIN_LED_GPIO            GPIO_NUM_NC
#define BOOT_BUTTON_GPIO            GPIO_NUM_0
#define TOUCH_BUTTON_GPIO           GPIO_NUM_NC
#define VOLUME_UP_BUTTON_GPIO       GPIO_NUM_NC
#define VOLUME_DOWN_BUTTON_GPIO     GPIO_NUM_NC


#define DISPLAY_BACKLIGHT_PIN       GPIO_NUM_46
#define DISPLAY_MOSI_PIN            GPIO_NUM_40
#define DISPLAY_MISO_PIN            GPIO_NUM_38
#define DISPLAY_CLK_PIN             GPIO_NUM_39
#define DISPLAY_DC_PIN              GPIO_NUM_21
#define DISPLAY_RST_PIN             GPIO_NUM_NC
#define DISPLAY_CS_PIN              GPIO_NUM_45

#define EXAMPLE_LCD_IO_SPI_CS       GPIO_NUM_45
#define EXAMPLE_LCD_IO_SPI_SCK      GPIO_NUM_39
#define EXAMPLE_LCD_IO_SPI_SDO      GPIO_NUM_40
#define EXAMPLE_LCD_IO_RGB_DE       GPIO_NUM_7
#define EXAMPLE_LCD_IO_RGB_PCLK     GPIO_NUM_6
#define EXAMPLE_LCD_IO_RGB_VSYNC    GPIO_NUM_4
#define EXAMPLE_LCD_IO_RGB_HSYNC    GPIO_NUM_5
#define EXAMPLE_LCD_IO_RGB_DISP 
#define EXAMPLE_LCD_IO_RGB_RESET    GPIO_NUM_NC
#define EXAMPLE_LCD_IO_RGB_R0       GPIO_NUM_12
#define EXAMPLE_LCD_IO_RGB_R1       GPIO_NUM_11
#define EXAMPLE_LCD_IO_RGB_R2       GPIO_NUM_8
#define EXAMPLE_LCD_IO_RGB_R3       GPIO_NUM_16
#define EXAMPLE_LCD_IO_RGB_R4       GPIO_NUM_15
#define EXAMPLE_LCD_IO_RGB_G0       GPIO_NUM_0
#define EXAMPLE_LCD_IO_RGB_G1       GPIO_NUM_14
#define EXAMPLE_LCD_IO_RGB_G2       GPIO_NUM_10
#define EXAMPLE_LCD_IO_RGB_G3       GPIO_NUM_9
#define EXAMPLE_LCD_IO_RGB_G4       GPIO_NUM_3
#define EXAMPLE_LCD_IO_RGB_G5       GPIO_NUM_13
#define EXAMPLE_LCD_IO_RGB_B0       GPIO_NUM_48
#define EXAMPLE_LCD_IO_RGB_B1       GPIO_NUM_47
#define EXAMPLE_LCD_IO_RGB_B2       GPIO_NUM_1
#define EXAMPLE_LCD_IO_RGB_B3       GPIO_NUM_21
#define EXAMPLE_LCD_IO_RGB_B4       GPIO_NUM_41



#define TOUCH_SDA_PIN               GPIO_NUM_17
#define TOUCH_SCL_PIN               GPIO_NUM_18

#define SDCARD_MOUNT_POINT          "/sdcard"
#define SDCARD_CS_PIN               GPIO_NUM_42





#define DISPLAY_WIDTH                   320
#define DISPLAY_HEIGHT                  840
#define DISPLAY_MIRROR_X                false
#define DISPLAY_MIRROR_Y                false
#define DISPLAY_SWAP_XY                 false
#define DISPLAY_INVERT_COLOR            true
#define DISPLAY_RGB_ORDER               LCD_RGB_ELEMENT_ORDER_RGB
#define DISPLAY_OFFSET_X                0
#define DISPLAY_OFFSET_Y                0
#define DISPLAY_BACKLIGHT_OUTPUT_INVERT false
#define DISPLAY_SPI_MODE                0



// A MCP Test: Control a lamp
#define LAMP_GPIO GPIO_NUM_18

#endif // _BOARD_CONFIG_H_

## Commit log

2022-06-29 Add hardware
    [ESP32-S3 Parallel TFT with Touch v1.0(3.5'' ili9488).brd, ESP32-S3 Parallel TFT with Touch v1.0(3.5'' ili9488).sch]
2024-07-12 add new version
    [ESP32-S3 Parallel TFT with Touch 3.5'' ili9488 v2.0.brd, ESP32-S3 Parallel TFT with Touch 3.5'' ili9488 v2.0.sch]
2024-07-12 Revert "Delete old version file."
    This reverts commit ae68940200865531560fb4ac1a0bfb5abab0bc47.
    [S3_Parallel16_ili9488.h]
2025-03-25 Add Arduino GFX Library display demo
2025-11-20 add esp-idf examples
    [partitions.csv]

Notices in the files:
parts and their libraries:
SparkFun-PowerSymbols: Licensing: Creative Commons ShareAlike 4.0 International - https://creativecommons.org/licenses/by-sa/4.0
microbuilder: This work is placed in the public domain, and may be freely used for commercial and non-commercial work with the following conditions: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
